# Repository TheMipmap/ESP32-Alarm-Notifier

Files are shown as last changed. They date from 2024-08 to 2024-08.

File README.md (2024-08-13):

# ESP32-Alarm-Notifier
An ESP32-based system for monitoring 24V analog alarm signals triggered by sensors throughout a farm. The software side of the system is made with ESPHome, Node-RED and Home Assistant. The ESP32 used is the Olimex ESP32-POE-ISO-IND, but any PoE powered ESP32 would have worked.

<Picture of the final setup>


## Problem description
There are 5 LEDs that represent alarms in different buildings. In order to find out whether a problem has occurred, and where said problem is, one must check these LEDs. The goal is to get these LEDs into Home Assistant as binary sensors, and notify me when a problem has occurred in any of the buildings. 

The five alarms can be simplified as seperate 24V circuits each containing an LED and an on/off switch.

<Picture of a simplified circuit>
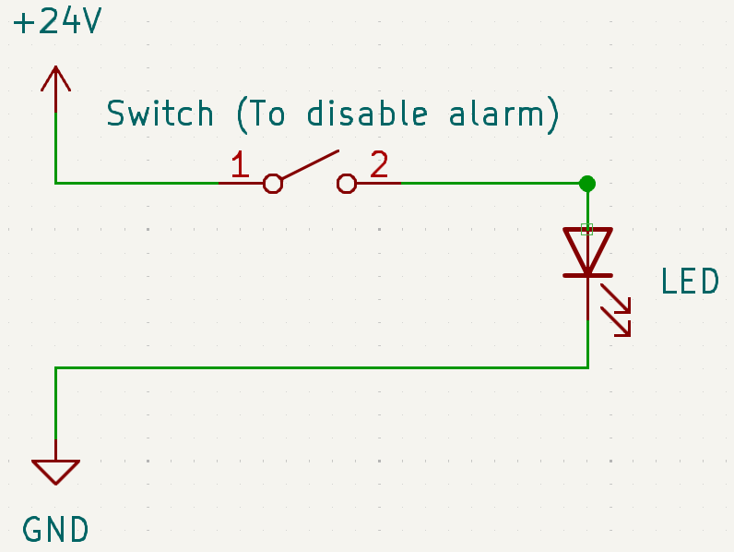
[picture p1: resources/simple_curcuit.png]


## Hardware & Solution
As I wanted to learn the basics of designing PCBs, I figured i could try to design a simple PCB that could solve this problem. Additionally, the ESP32 had to be powered using PoE (to minimize cabling). After searching for boards around the internet, I settled for the Olimex ESP32-POE board. The idea was simple. I wanted to intercept the signal on each LED using optocouplers. The collectors were connected to their own GPIO pin, with ESP32's internal pullup resistors, and the emitters were connected to ground. The simplified circuit with an optocoupler can be seen in the picture below.

<Picture of simplified circuit with opto>
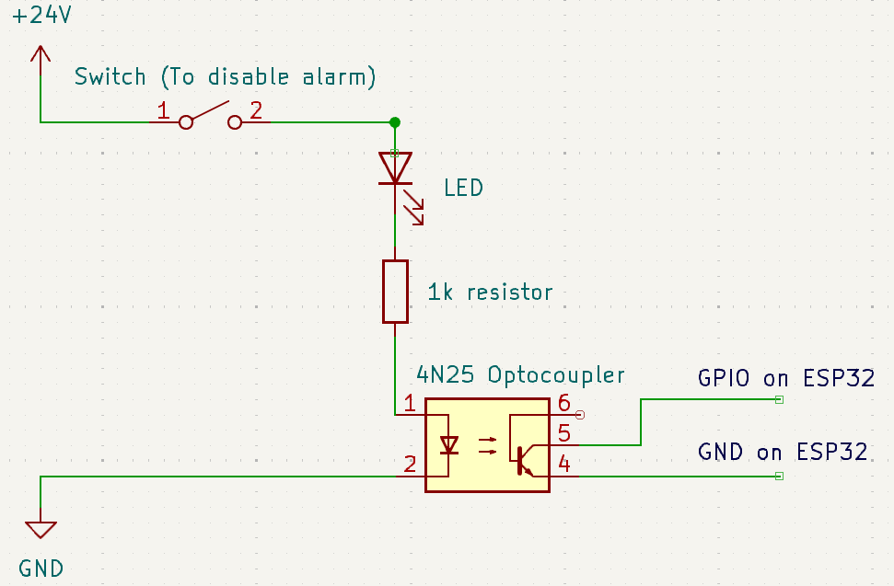
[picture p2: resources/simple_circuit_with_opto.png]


The KiCAD files for the final design of the PCB can be found in the repository. 

<Picture of the PCB schematics>
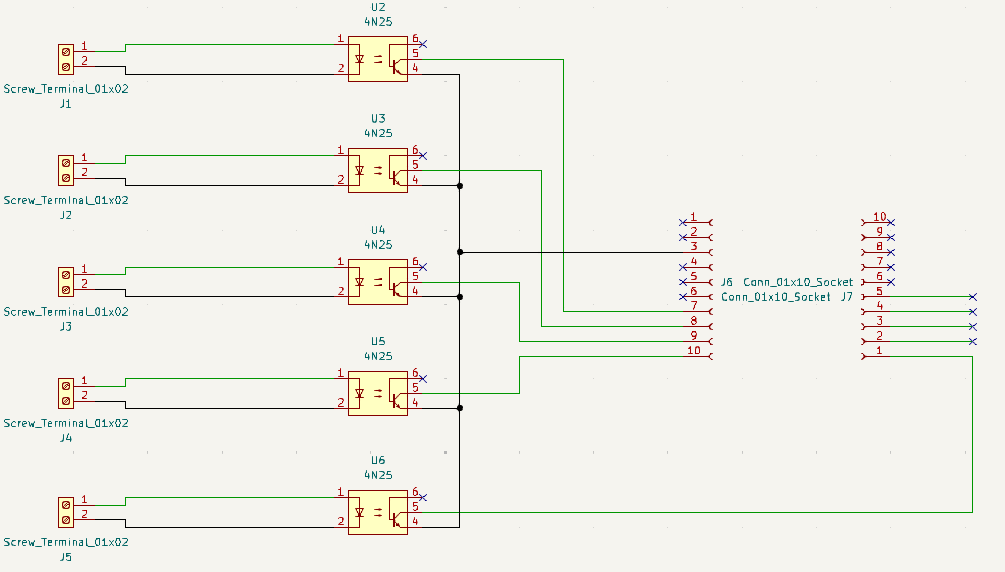
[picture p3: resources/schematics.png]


<Picture of the PCB circuit>
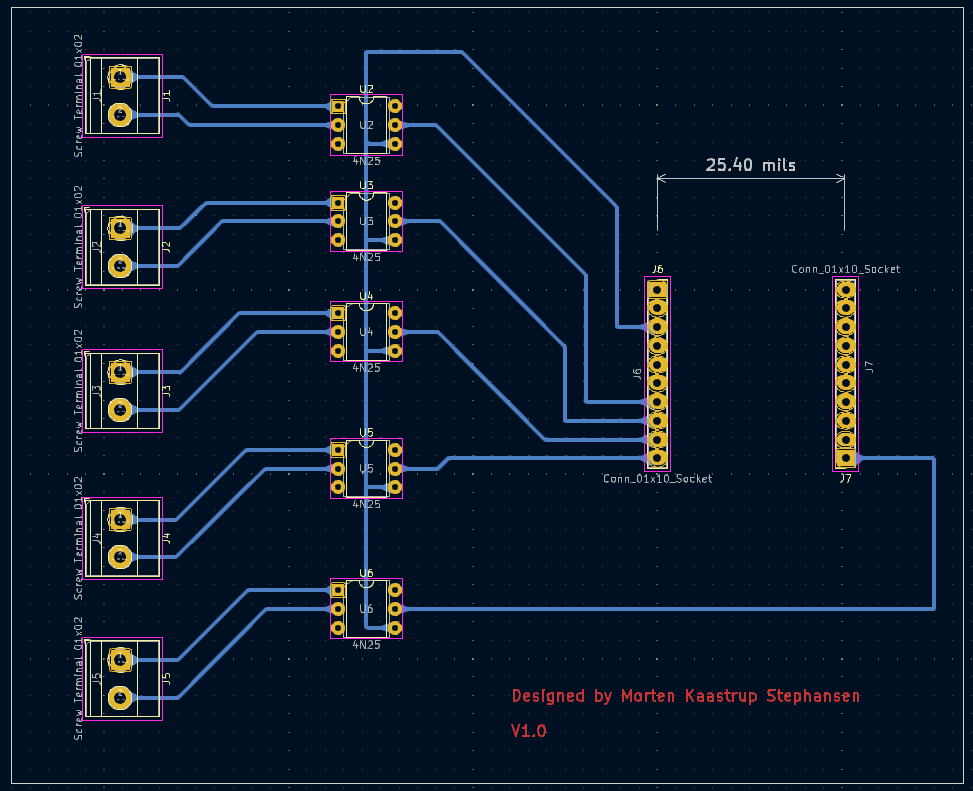
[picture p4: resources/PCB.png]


<Render of the PCB in KiCAD>
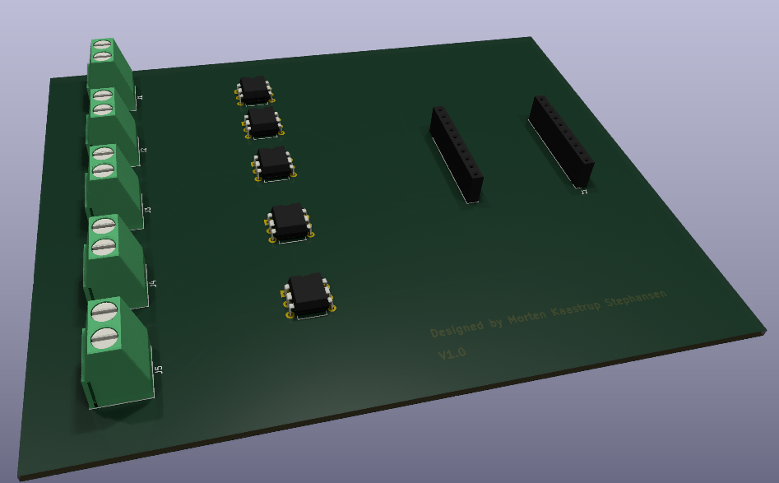
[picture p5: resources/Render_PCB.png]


<Picture of the PCB with components>


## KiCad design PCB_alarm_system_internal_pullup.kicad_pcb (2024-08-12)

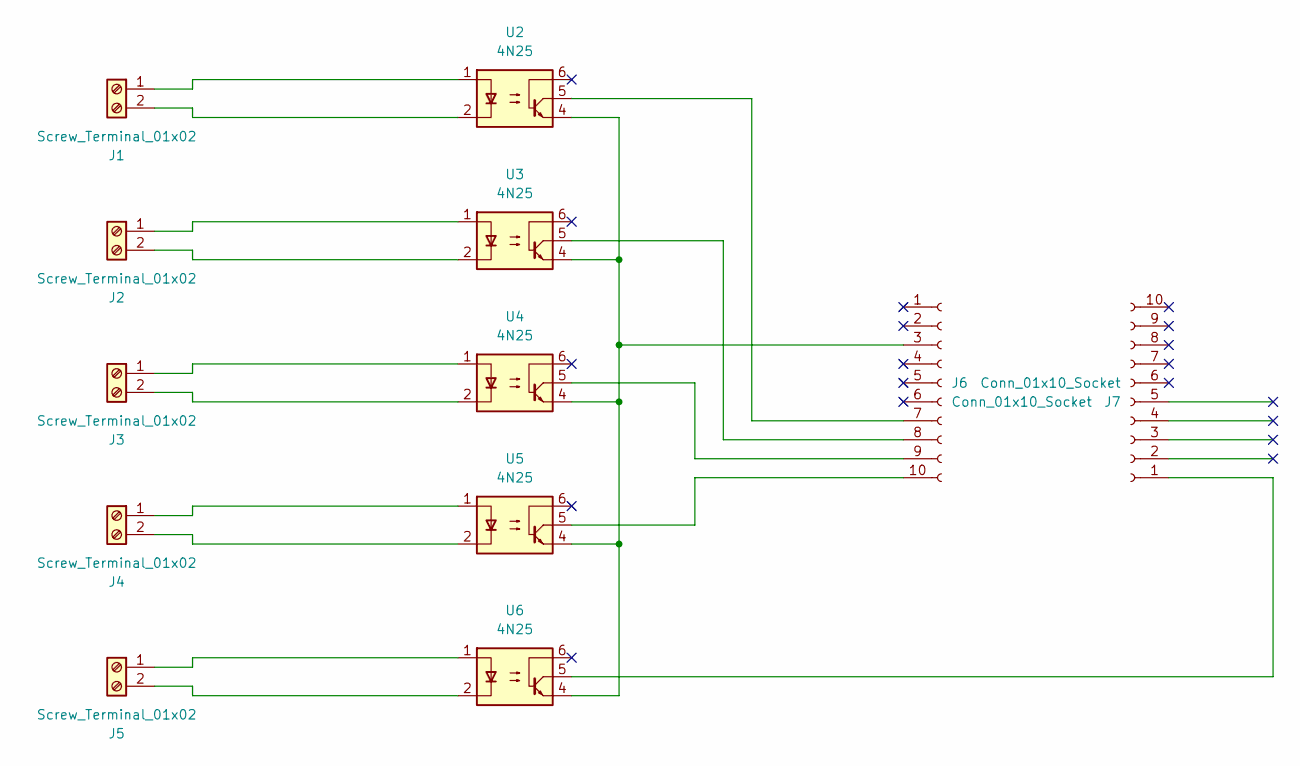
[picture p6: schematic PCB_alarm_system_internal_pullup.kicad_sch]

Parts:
J1, J2, J3, J4, J5: Screw_Terminal_01x02; TerminalBlock_Phoenix_MKDS-1,5-2-5.08_1x02_P5.08mm_Horizont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
J6, J7: Conn_01x10_Socket; PinSocket_1x10_P2.54mm_Vertical
U2, U3, U4, U5, U6: 4N25; DIP-6_W7.62mm

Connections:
unnamed: J1.1, U2.1
unnamed: J1.2, U2.2
unnamed: J2.1, U3.1
unnamed: J2.2, U3.2
unnamed: J3.1, U4.1
unnamed: J3.2, U4.2
unnamed: J4.1, U5.1
unnamed: J4.2, U5.2
unnamed: J5.1, U6.1
unnamed: J5.2, U6.2
unnamed: J6.3, U2.4, U3.4, U4.4, U5.4, U6.4
unnamed: J6.7, U2.5
unnamed: J6.8, U3.5
unnamed: J6.9, U4.5
unnamed: J6.10, U5.5
unnamed: J7.1, U6.5

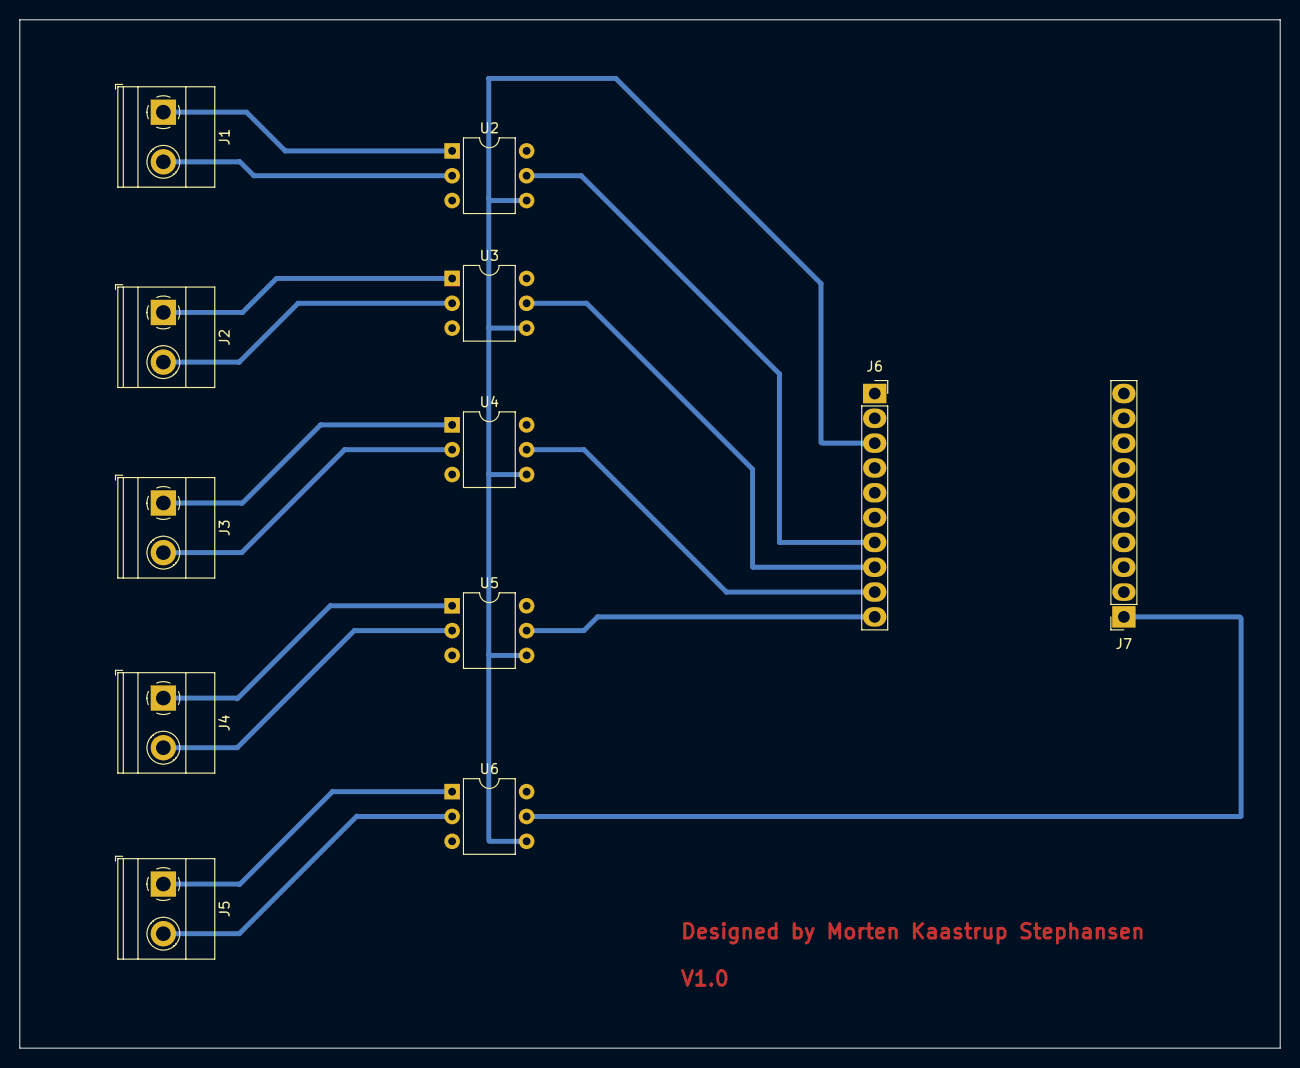
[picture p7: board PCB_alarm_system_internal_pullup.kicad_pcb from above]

Board: 2 copper layers, 129.0 x 105.2 mm, 12 parts (0 on the bottom side), 16 nets.

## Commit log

2024-08-12 Added resources and KiCAD files
    [PCB_alarm_system_internal_pullup.kicad_pcb, PCB_alarm_system_internal_pullup.kicad_sch]
2024-08-13 Added picture of the PCB with component
